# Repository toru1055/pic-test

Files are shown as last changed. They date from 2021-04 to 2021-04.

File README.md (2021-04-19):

# pic-test

## プッシュでラジオ体操
### 1. sin波で音楽再生
  - [x] オーディオアンプなし版
    - [x] 020 一定間隔でLEDを点滅させたい（MCCでタイマ設定）
    - [x] 075 MCCでオペアンプを設定して使いたい
    - [x] 101 正弦波を出力したい
  - [ ] オーディオアンプあり版

### 2. SPI通信でフラッシュメモリ読み書き
  - [x] 071 MCCでUSARTを設定して使いたい
    - [x] `$ screen /dev/tty.usbserial-0001 9600`
  - [x] 074 MCCでSPIを設定して使いたい
  - [x] 051 SPI接続の大容量フラッシュメモリを使いたい

### 3. フラッシュメモリから音声データを再生
  - [x] WAV形式のフォーマットを理解する
  - [x] `$ xxd 1164_8bit.wav | head`を見れば大体わかるが、データ部は80バイト目くらいからなので80バイトオフセットすれば良さそう
  - [x] [wav converter](https://audio.online-convert.com/convert-to-wav): 8bit モノラルの1000Hzに変換
  - [x] 104 WAVファイルをフラッシュメモリに書き込みたい
    - [x] windowsのteratermが最適。
  - [x] 103 WAVファイルの音楽を再生したい

### 4. ボタン割り込み制御：ボタンを押したら対応する音声ファイルを割り込み再生
- [x] Pin ManagerでIOC対象のPINを設定
- [x] Timer割り込みではなく、通常のDelayメソッドで音楽再生するメソッドを用意
- [x] Interrupt Handlerを実装して設定する
- [x] 1, 2番pinを押したら再生

### 5. 仕上げ
- [ ] ラジオ体操の音源を入れる
- [ ] PCBの設計

### 6. 音源をWAV形式で用意する
#### ffmpegをインストール
```
$ brew install homebrew-ffmpeg/ffmpeg/ffmpeg
```

#### mp3音源を連結する
```
$ for f in *.mp3; do echo "file '$f'" >> mylist.txt; done
$ ffmpeg -f concat -safe 0 -i mylist.txt -c copy output.mp3
```

#### MP3→WAV(8kHz,8bit,mono)へ変換
```
$ ffmpeg -i output.mp3 -ac 1 -ar 8000 -acodec pcm_u8 output.wav
```

## 音声ファイルのwifiアップロード
### 1. esp-wroom-02でアップロードされたファイルをSPI通信でフラッシュメモリ書き込み

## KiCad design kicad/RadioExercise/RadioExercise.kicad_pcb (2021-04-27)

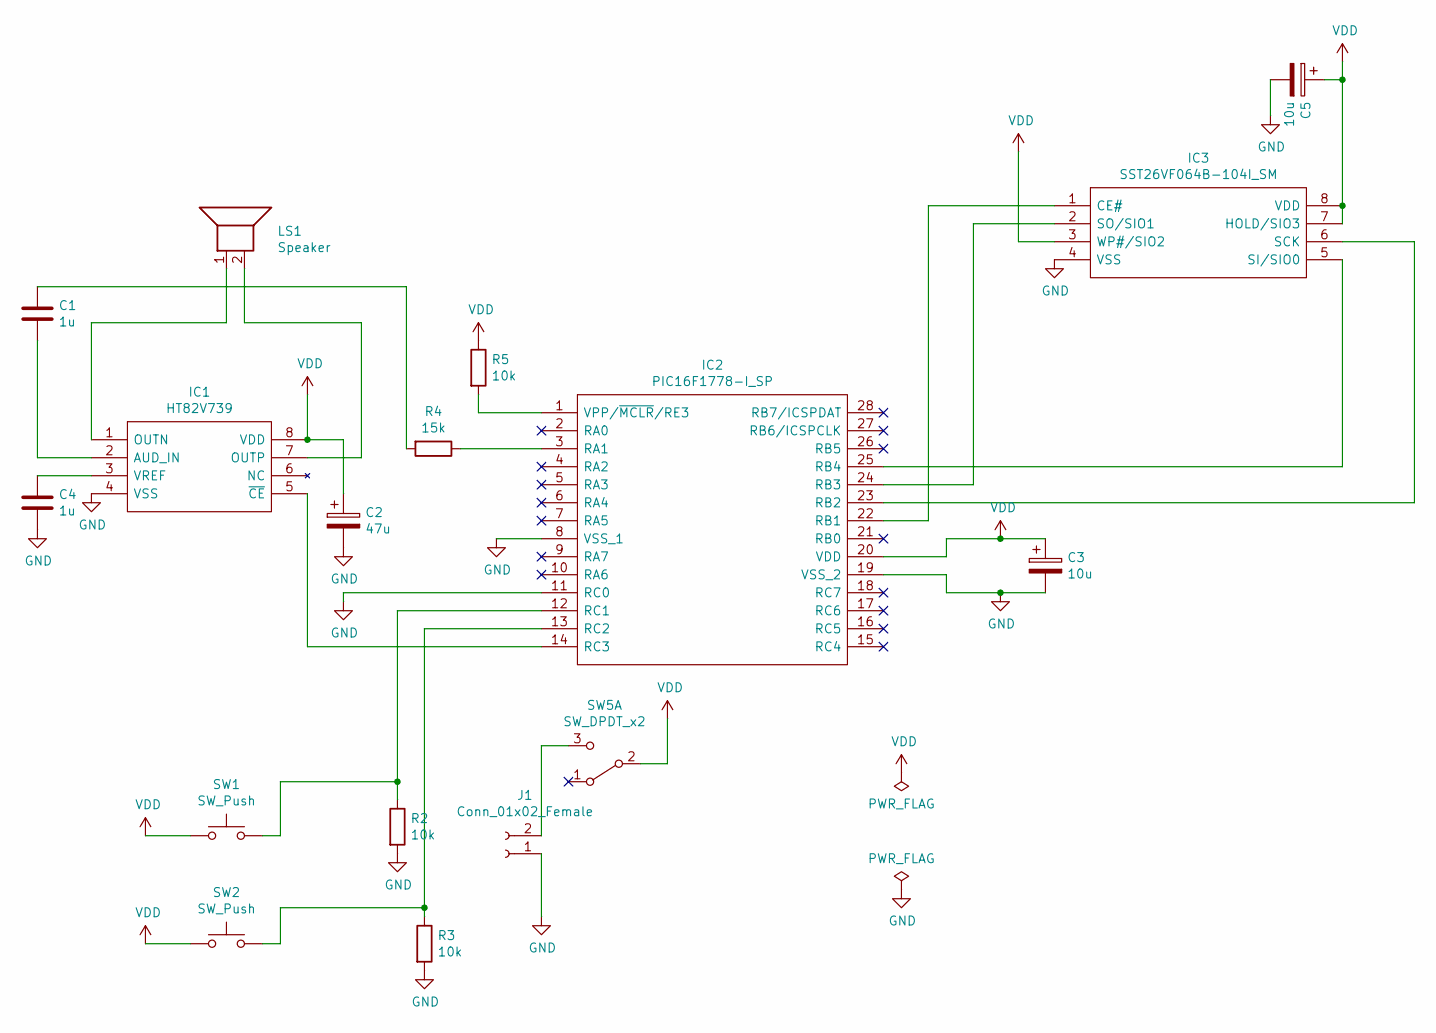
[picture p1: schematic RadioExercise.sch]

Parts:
C1, C4: 1u; C_Disc_D7.5mm_W5.0mm_P5.00mm
C2: 47u; CP_Radial_D4.0mm_P1.50mm
C3, C5: 10u; CP_Radial_D4.0mm_P1.50mm
IC1: HT82V739; DIP-8_W7.62mm; Manufacturer_Part_Number HT82V739
IC2: PIC16F1778-I_SP; DIP794W56P254L3486H508Q28N; Manufacturer_Part_Number PIC16F1778-I/SP; Mouser Part Number 579-PIC16F1778-I/SP
IC3: SST26VF064B-104I_SM; SOIC127P794X203-8N; Manufacturer_Part_Number SST26VF064B-104I/SM; Mouser Part Number 579-ST26VF064B104ISM
J1: Conn_01x02_Female; Conn_01x02_SMD
LS1: Speaker; Conn_01x02_SMD
R2, R3, R5: 10k; R_Axial_DIN0207_L6.3mm_D2.5mm_P7.62mm_Horizontal
R4: 15k; R_Axial_DIN0207_L6.3mm_D2.5mm_P7.62mm_Horizontal
SW1, SW2: SW_Push; SW_PUSH_6mm
SW5: SW_DPDT_x2; SW_slide_01x03_THT

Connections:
GND: C2.2, C3.2, C4.2, C5.2, IC1.4 (VSS), IC2.8 (VSS_1), IC2.11 (RC0), IC2.19 (VSS_2), IC3.4 (VSS), J1.1, R2.2, R3.2
unnamed: C1.1, R4.2
unnamed: C1.2, IC1.2 (AUD_IN)
unnamed: C4.1, IC1.3 (VREF)
unnamed: IC1.1 (OUTN), LS1.1
unnamed: IC1.5 (~CE), IC2.14 (RC3)
unnamed: IC1.7 (OUTP), LS1.2
unnamed: IC2.1 (VPP/~MCLR~/RE3), R5.2
unnamed: IC2.3 (RA1), R4.1
unnamed: IC2.12 (RC1), R2.1, SW1.2
unnamed: IC2.13 (RC2), R3.1, SW2.2
unnamed: IC2.22 (RB1), IC3.1 (CE#)
unnamed: IC2.23 (RB2), IC3.6 (SCK)
unnamed: IC2.24 (RB3), IC3.2 (SO/SIO1)
unnamed: IC2.25 (RB4), IC3.5 (SI/SIO0)
unnamed: J1.2, SW5.3 (C)
VDD: C2.1, C3.1, C5.1, IC1.8 (VDD), IC2.20 (VDD), IC3.3 (WP#/SIO2), IC3.7 (HOLD/SIO3), IC3.8 (VDD), R5.1, SW1.1, SW2.1, SW5.2 (B)

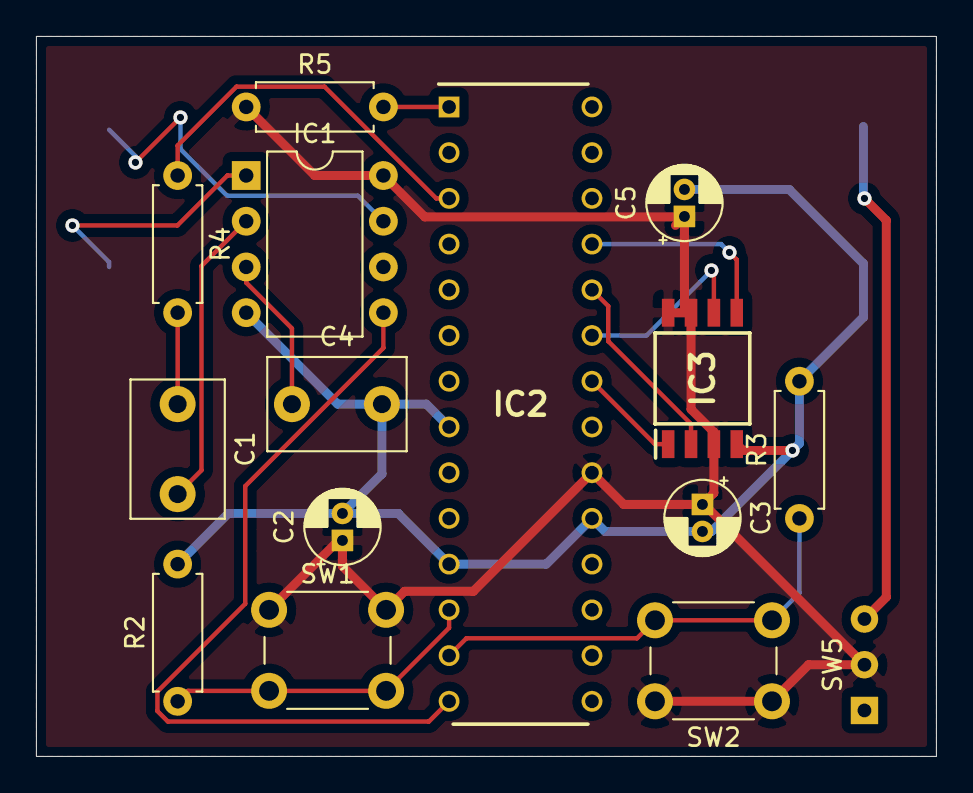
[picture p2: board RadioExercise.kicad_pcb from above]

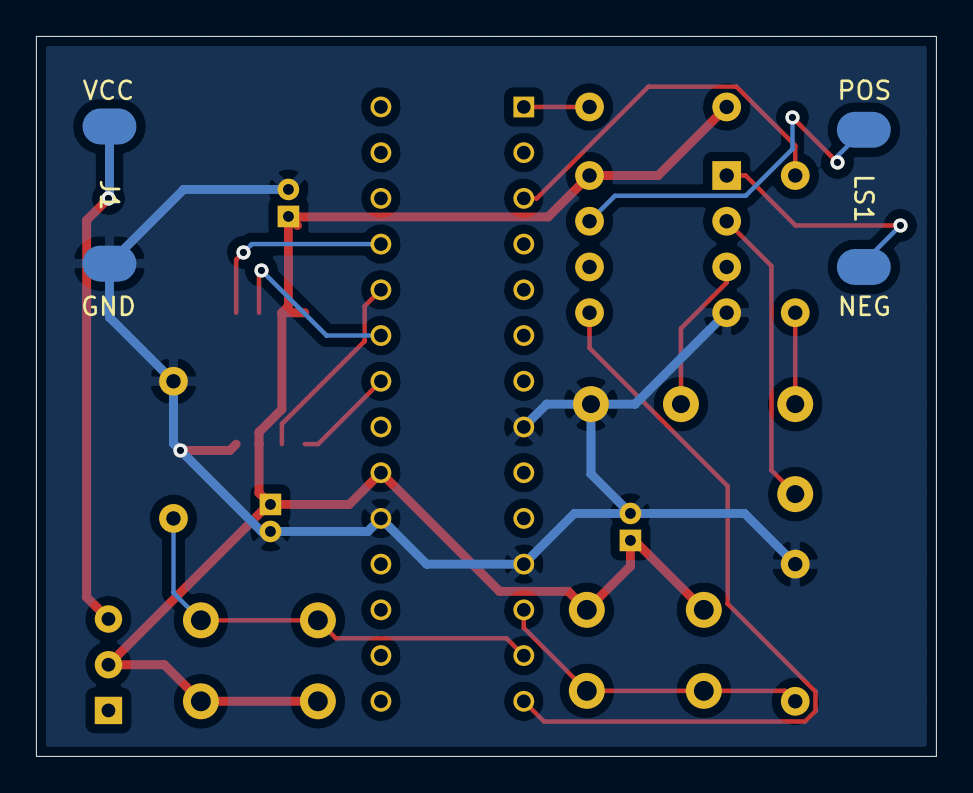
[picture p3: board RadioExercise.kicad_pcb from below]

Board: 2 copper layers, 50.0 x 40.0 mm, 17 parts (2 on the bottom side), 17 nets.

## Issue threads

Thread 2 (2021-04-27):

反省点まとめ

toru1055, 2021-04-27:
- 基盤にスペーサー用のスペースを用意すべきだった
- 基盤固定用に穴をあけてもよかったかも
- 電源とスピーカー用のPAD付近に余白を用意すればはんだしやすい
- スピーカーは基盤の表面や裏面に貼り付けるスタイルでも良かった
- オーディオアンプの電源付近に電解コンデンサを置く
- フラッシュメモリ付近はハサミではさめるスペースを確保（データ書き換え）
- STOPボタン（RESET）を置いても良かった
- 電池ケースの配線はちょうどいい長さに切っておく

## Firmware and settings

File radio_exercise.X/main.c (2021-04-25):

/**
  Generated Main Source File

  Company:
    Microchip Technology Inc.

  File Name:
    main.c

  Summary:
    This is the main file generated using PIC10 / PIC12 / PIC16 / PIC18 MCUs

  Description:
    This header file provides implementations for driver APIs for all modules selected in the GUI.
    Generation Information :
        Product Revision  :  PIC10 / PIC12 / PIC16 / PIC18 MCUs - 1.81.7
        Device            :  PIC16F1778
        Driver Version    :  2.00
*/

/*
    (c) 2018 Microchip Technology Inc. and its subsidiaries. 
    
    Subject to your compliance with these terms, you may use Microchip software and any 
    derivatives exclusively with Microchip products. It is your responsibility to comply with third party 
    license terms applicable to your use of third party software (including open source software) that 
    may accompany Microchip software.
    
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
    IN NO EVENT WILL MICROCHIP BE LIABLE FOR ANY INDIRECT, SPECIAL, PUNITIVE, 
    INCIDENTAL OR CONSEQUENTIAL LOSS, DAMAGE, COST OR EXPENSE OF ANY KIND 
    WHATSOEVER RELATED TO THE SOFTWARE, HOWEVER CAUSED, EVEN IF MICROCHIP 
    HAS BEEN ADVISED OF THE POSSIBILITY OR THE DAMAGES ARE FORESEEABLE. TO 
    THE FULLEST EXTENT ALLOWED BY LAW, MICROCHIP'S TOTAL LIABILITY ON ALL 
    CLAIMS IN ANY WAY RELATED TO THIS SOFTWARE WILL NOT EXCEED THE AMOUNT 
    OF FEES, IF ANY, THAT YOU HAVE PAID DIRECTLY TO MICROCHIP FOR THIS 
    SOFTWARE.
*/

#include "mcc_generated_files/mcc.h"

#define INNER_FLASH_ADDRESS 0x3F80
#define SONG_DATA_ADDRESS 0x0600
#define SONG_SETTING_ADDRESS 0x0500 // TODO: 0x0000に変更

uint8_t playing_song = 0;
uint32_t saving_address = SONG_DATA_ADDRESS;

void CS_SetLow() {
    RB1 = 0;
}
void CS_SetHigh() {
    RB1 = 1;
}
void SendAdrs(uint32_t address) {
    SPI_ExchangeByte((uint8_t)(address>>16));
    SPI_ExchangeByte((uint8_t)(address>>8));
    SPI_ExchangeByte((uint8_t)(address));
}

uint8_t SPIFlashByteReadOnce(uint32_t address) {
    uint8_t data;
    CS_SetLow();
    SPI_ExchangeByte(0x03);
    SendAdrs(address);
    data = SPI_ExchangeByte(0xAA);
    CS_SetHigh();
    return data;
}


void SPIFlashReadOpen(uint32_t address) {
    CS_SetLow();
    SPI_ExchangeByte(0x03);
    SendAdrs(address);
}
void SPIFlashReadClose(void) {
    CS_SetHigh();
}
uint8_t SPIFlashByteRead(void) {
    return SPI_ExchangeByte(0xAA);
}


void SPIFlashByteWrite(uint32_t address, uint8_t data) {
    CS_SetLow();
    SPI_ExchangeByte(0x06); // Write Enable
    CS_SetHigh();
    CS_SetLow();
    SPI_ExchangeByte(0x02);
    SendAdrs(address);
    SPI_ExchangeByte(data);
    CS_SetHigh();
    __delay_ms(2);
}

void SPIFlashErase(void) {
    CS_SetLow();
    SPI_ExchangeByte(0x06);
    CS_SetHigh();
    __delay_ms(50);
    CS_SetLow();
    SPI_ExchangeByte(0xC7);
    CS_SetHigh();
    __delay_ms(50);
}

void SPIFlashUnprotect(void) {
    uint8_t i;
    CS_SetLow();
    SPI_ExchangeByte(0x06);
    CS_SetHigh();
    __delay_ms(50);
    CS_SetLow();
    SPI_ExchangeByte(0x42);
    for(i=0; i < 18; i++) {
        SPI_ExchangeByte(0x00);
    }
    CS_SetHigh();
    __delay_ms(50);
}

void save_end_address(uint16_t song_num, uint32_t end_address) {
    uint16_t Buf[ERASE_FLASH_BLOCKSIZE];
    FLASH_WriteWord((song_num*0x010) + INNER_FLASH_ADDRESS + 0x000, Buf, (uint8_t)(end_address>>16));
    FLASH_WriteWord((song_num*0x010) + INNER_FLASH_ADDRESS + 0x001, Buf, (uint8_t)(end_address>>8));
    FLASH_WriteWord((song_num*0x010) + INNER_FLASH_ADDRESS + 0x002, Buf, (uint8_t)(end_address>>0));
}

void save_end_address_spi(uint32_t song_num, uint32_t end_address) {
    SPIFlashByteWrite(SONG_SETTING_ADDRESS + (song_num*0x010) + 0x000, (uint8_t)(end_address>>16));
    SPIFlashByteWrite(SONG_SETTING_ADDRESS + (song_num*0x010) + 0x001, (uint8_t)(end_address>>8));
    SPIFlashByteWrite(SONG_SETTING_ADDRESS + (song_num*0x010) + 0x002, (uint8_t)(end_address>>0));
}

uint32_t load_end_address_spi(uint32_t song_num) {
    uint32_t end_address = SPIFlashByteReadOnce(SONG_SETTING_ADDRESS + (song_num*0x010) + 0x000);
    end_address = (end_address<<8) + (uint32_t)SPIFlashByteReadOnce(SONG_SETTING_ADDRESS + (song_num*0x010) + 0x001);
    end_address = (end_address<<8) + (uint32_t)SPIFlashByteReadOnce(SONG_SETTING_ADDRESS + (song_num*0x010) + 0x002);
    return end_address;
}

void save_1st_music(void) {
    save_end_address_spi(1, saving_address);
}

void save_2nd_music(void) {
    save_end_address_spi(2, saving_address);
}

void save_music(void) {
    uint8_t data;
    saving_address = SONG_DATA_ADDRESS;
    SPI_Open(SPI_DEFAULT);
    //SPIFlashUnprotect();
    SPIFlashErase();
    while(1) {
        data = getch();
        SPIFlashByteWrite(saving_address++, data);
    }
    SPI_Close();
}

void save_music_dummy(void) {
    SPI_Open(SPI_DEFAULT);
    SPIFlashUnprotect();
    CS_SetLow();
    SPI_ExchangeByte(0x20);
    SendAdrs(SONG_SETTING_ADDRESS);
    CS_SetHigh();
    save_end_address_spi(1, 120000);
    save_end_address_spi(2, 240000);
    SPI_Close();
}

uint32_t load_end_address(uint16_t song_num) {
    uint32_t end_address = FLASH_ReadWord((song_num*0x010) + INNER_FLASH_ADDRESS + 0x000);
    end_address = (end_address<<8) + (uint32_t)FLASH_ReadWord((song_num*0x010) + INNER_FLASH_ADDRESS + 0x001);
    end_address = (end_address<<8) + (uint32_t)FLASH_ReadWord((song_num*0x010) + INNER_FLASH_ADDRESS + 0x002);
    return end_address;
}

void play_music(void) {
    uint8_t data;
    uint32_t counter = 0;
    SPI_Open(SPI_DEFAULT);
    SPIFlashReadOpen(80);
    while(1) {
        while(PIR1bits.TMR2IF == 0);
        PIR1bits.TMR2IF = 0;
        data = SPIFlashByteRead();
        DAC1_Load10bitInputData(data);
        if (counter++ >= 240000) {
            counter = 0;
            SPIFlashReadClose();
            RB5 = 1;
            __delay_ms(3000);
            RB5 = 0;
            SPIFlashReadOpen(80);
        }
    }
    SPI_Close();
}

void play_music_once(uint32_t song_num) {
    uint32_t from_address;
    uint32_t to_address;
    uint32_t i;
    uint8_t data;
    RC3 = 0;
    CS_SetHigh();
    SPI_Open(SPI_DEFAULT);
    if (song_num < 2) {
        from_address = SONG_DATA_ADDRESS;
    } else {
        from_address = load_end_address_spi(song_num - 1) + 1;
    }
    to_address = load_end_address_spi(song_num);
    SPIFlashReadOpen(from_address);
    for (i = from_address; i < to_address; i++) {
        while(PIR1bits.TMR2IF == 0);
        PIR1bits.TMR2IF = 0;
        data = SPIFlashByteRead();
        DAC1_Load10bitInputData(data);
    }
    SPIFlashReadClose();
    SPI_Close();
    RC3 = 1;
}

void play_1st_music(void) {
    play_music_once(1);
}

void play_2nd_music(void) {
    play_music_once(2);
}

/*
                         Main application
 */
void main(void)
{
    SYSTEM_Initialize();
    RC3 = 1;
    CS_SetHigh();
    ei();
    if (RC0) {
        RB5 = 1;
        __delay_ms(100);
        IOCCF1_SetInterruptHandler(save_1st_music);
        IOCCF2_SetInterruptHandler(save_2nd_music);
        save_music();
//        save_music_dummy();
    } else {
        IOCCF1_SetInterruptHandler(play_1st_music);
        IOCCF2_SetInterruptHandler(play_2nd_music);
        while(1) {
            SLEEP();
        }
    } 
}
/**
 End of File
*/

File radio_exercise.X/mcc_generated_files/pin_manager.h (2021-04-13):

/**
  @Generated Pin Manager Header File

  @Company:
    Microchip Technology Inc.

  @File Name:
    pin_manager.h

  @Summary:
    This is the Pin Manager file generated using PIC10 / PIC12 / PIC16 / PIC18 MCUs

  @Description
    This header file provides APIs for driver for .
    Generation Information :
        Product Revision  :  PIC10 / PIC12 / PIC16 / PIC18 MCUs - 1.81.7
        Device            :  PIC16F1778
        Driver Version    :  2.11
    The generated drivers are tested against the following:
        Compiler          :  XC8 2.31 and above
        MPLAB 	          :  MPLAB X 5.45	
*/

/*
    (c) 2018 Microchip Technology Inc. and its subsidiaries. 
    
    Subject to your compliance with these terms, you may use Microchip software and any 
    derivatives exclusively with Microchip products. It is your responsibility to comply with third party 
    license terms applicable to your use of third party software (including open source software) that 
    may accompany Microchip software.
    
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
    IN NO EVENT WILL MICROCHIP BE LIABLE FOR ANY INDIRECT, SPECIAL, PUNITIVE, 
    INCIDENTAL OR CONSEQUENTIAL LOSS, DAMAGE, COST OR EXPENSE OF ANY KIND 
    WHATSOEVER RELATED TO THE SOFTWARE, HOWEVER CAUSED, EVEN IF MICROCHIP 
    HAS BEEN ADVISED OF THE POSSIBILITY OR THE DAMAGES ARE FORESEEABLE. TO 
    THE FULLEST EXTENT ALLOWED BY LAW, MICROCHIP'S TOTAL LIABILITY ON ALL 
    CLAIMS IN ANY WAY RELATED TO THIS SOFTWARE WILL NOT EXCEED THE AMOUNT 
    OF FEES, IF ANY, THAT YOU HAVE PAID DIRECTLY TO MICROCHIP FOR THIS 
    SOFTWARE.
*/

#ifndef PIN_MANAGER_H
#define PIN_MANAGER_H

/**
  Section: Included Files
*/

#include <xc.h>

#define INPUT   1
#define OUTPUT  0

#define HIGH    1
#define LOW     0

#define ANALOG      1
#define DIGITAL     0

#define PULL_UP_ENABLED      1
#define PULL_UP_DISABLED     0

// get/set RA1 procedures
#define RA1_SetHigh()            do { LATAbits.LATA1 = 1; } while(0)
#define RA1_SetLow()             do { LATAbits.LATA1 = 0; } while(0)
#define RA1_Toggle()             do { LATAbits.LATA1 = ~LATAbits.LATA1; } while(0)
#define RA1_GetValue()              PORTAbits.RA1
#define RA1_SetDigitalInput()    do { TRISAbits.TRISA1 = 1; } while(0)
#define RA1_SetDigitalOutput()   do { TRISAbits.TRISA1 = 0; } while(0)
#define RA1_SetPullup()             do { WPUAbits.WPUA1 = 1; } while(0)
#define RA1_ResetPullup()           do { WPUAbits.WPUA1 = 0; } while(0)
#define RA1_SetAnalogMode()         do { ANSELAbits.ANSA1 = 1; } while(0)
#define RA1_SetDigitalMode()        do { ANSELAbits.ANSA1 = 0; } while(0)

// get/set RA5 procedures
#define RA5_SetHigh()            do { LATAbits.LATA5 = 1; } while(0)
#define RA5_SetLow()             do { LATAbits.LATA5 = 0; } while(0)
#define RA5_Toggle()             do { LATAbits.LATA5 = ~LATAbits.LATA5; } while(0)
#define RA5_GetValue()              PORTAbits.RA5
#define RA5_SetDigitalInput()    do { TRISAbits.TRISA5 = 1; } while(0)
#define RA5_SetDigitalOutput()   do { TRISAbits.TRISA5 = 0; } while(0)
#define RA5_SetPullup()             do { WPUAbits.WPUA5 = 1; } while(0)
#define RA5_ResetPullup()           do { WPUAbits.WPUA5 = 0; } while(0)
#define RA5_SetAnalogMode()         do { ANSELAbits.ANSA5 = 1; } while(0)
#define RA5_SetDigitalMode()        do { ANSELAbits.ANSA5 = 0; } while(0)

// get/set RB0 procedures
#define RB0_SetHigh()            do { LATBbits.LATB0 = 1; } while(0)
#define RB0_SetLow()             do { LATBbits.LATB0 = 0; } while(0)
#define RB0_Toggle()             do { LATBbits.LATB0 = ~LATBbits.LATB0; } while(0)
#define RB0_GetValue()              PORTBbits.RB0
#define RB0_SetDigitalInput()    do { TRISBbits.TRISB0 = 1; } while(0)
#define RB0_SetDigitalOutput()   do { TRISBbits.TRISB0 = 0; } while(0)
#define RB0_SetPullup()             do { WPUBbits.WPUB0 = 1; } while(0)
#define RB0_ResetPullup()           do { WPUBbits.WPUB0 = 0; } while(0)
#define RB0_SetAnalogMode()         do { ANSELBbits.ANSB0 = 1; } while(0)
#define RB0_SetDigitalMode()        do { ANSELBbits.ANSB0 = 0; } while(0)

// get/set IO_RB1 aliases
#define IO_RB1_TRIS                 TRISBbits.TRISB1
#define IO_RB1_LAT                  LATBbits.LATB1
#define IO_RB1_PORT                 PORTBbits.RB1
#define IO_RB1_WPU                  WPUBbits.WPUB1
#define IO_RB1_ANS                  ANSELBbits.ANSB1
#define IO_RB1_SetHigh()            do { LATBbits.LATB1 = 1; } while(0)
#define IO_RB1_SetLow()             do { LATBbits.LATB1 = 0; } while(0)
#define IO_RB1_Toggle()             do { LATBbits.LATB1 = ~LATBbits.LATB1; } while(0)
#define IO_RB1_GetValue()           PORTBbits.RB1
#define IO_RB1_SetDigitalInput()    do { TRISBbits.TRISB1 = 1; } while(0)
#define IO_RB1_SetDigitalOutput()   do { TRISBbits.TRISB1 = 0; } while(0)
#define IO_RB1_SetPullup()          do { WPUBbits.WPUB1 = 1; } while(0)
#define IO_RB1_ResetPullup()        do { WPUBbits.WPUB1 = 0; } while(0)
#define IO_RB1_SetAnalogMode()      do { ANSELBbits.ANSB1 = 1; } while(0)
#define IO_RB1_SetDigitalMode()     do { ANSELBbits.ANSB1 = 0; } while(0)

// get/set RB2 procedures
#define RB2_SetHigh()            do { LATBbits.LATB2 = 1; } while(0)
#define RB2_SetLow()             do { LATBbits.LATB2 = 0; } while(0)
#define RB2_Toggle()             do { LATBbits.LATB2 = ~LATBbits.LATB2; } while(0)
#define RB2_GetValue()              PORTBbits.RB2
#define RB2_SetDigitalInput()    do { TRISBbits.TRISB2 = 1; } while(0)
#define RB2_SetDigitalOutput()   do { TRISBbits.TRISB2 = 0; } while(0)
#define RB2_SetPullup()             do { WPUBbits.WPUB2 = 1; } while(0)
#define RB2_ResetPullup()           do { WPUBbits.WPUB2 = 0; } while(0)
#define RB2_SetAnalogMode()         do { ANSELBbits.ANSB2 = 1; } while(0)
#define RB2_SetDigitalMode()        do { ANSELBbits.ANSB2 = 0; } while(0)

// get/set RB3 procedures
#define RB3_SetHigh()            do { LATBbits.LATB3 = 1; } while(0)
#define RB3_SetLow()             do { LATBbits.LATB3 = 0; } while(0)
#define RB3_Toggle()             do { LATBbits.LATB3 = ~LATBbits.LATB3; } while(0)
#define RB3_GetValue()              PORTBbits.RB3
#define RB3_SetDigitalInput()    do { TRISBbits.TRISB3 = 1; } while(0)
#define RB3_SetDigitalOutput()   do { TRISBbits.TRISB3 = 0; } while(0)
#define RB3_SetPullup()             do { WPUBbits.WPUB3 = 1; } while(0)
#define RB3_ResetPullup()           do { WPUBbits.WPUB3 = 0; } while(0)
#define RB3_SetAnalogMode()         do { ANSELBbits.ANSB3 = 1; } while(0)
#define RB3_SetDigitalMode()        do { ANSELBbits.ANSB3 = 0; } while(0)
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

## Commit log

2021-04-03 add spi methods
2021-04-09 割り込みで音源再生するように修正
2021-04-10 ボタン制御可能に
2021-04-10 add memory but not working
    [main.c]
2021-04-10 割り込み
2021-04-11 内蔵フラッシュメモリに保存できるようにした1
2021-04-11 オーディオアンプのON/OFF制御
2021-04-12 オーディオアンプを待機中OFFに
2021-04-13 add kicad dir
    [RadioExercise.kicad_pcb, RadioExercise.sch]
2021-04-15 SPIフラッシュに曲設定を保存するように変更
2021-04-15 remove wire
    [RadioExercise.kicad_pcb]
2021-04-15 add 2x2
    [RadioExercise_2x2-B_Cu.gbl, RadioExercise_2x2-B_Mask.gbs, RadioExercise_2x2-B_Paste.gbp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]
2021-04-16 add music_writer
    [RadioExercise.sch]
2021-04-27 配線が繋がってなかったので修正
    [RadioExercise.kicad_pcb]
